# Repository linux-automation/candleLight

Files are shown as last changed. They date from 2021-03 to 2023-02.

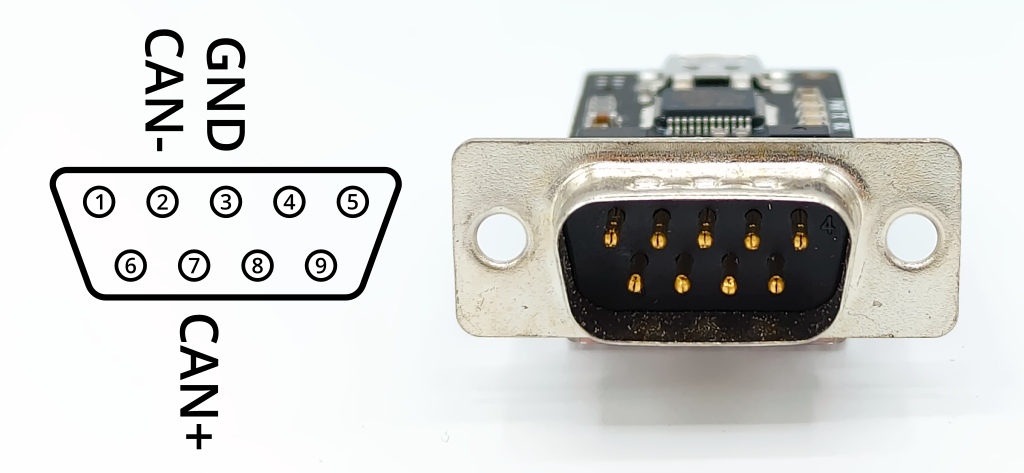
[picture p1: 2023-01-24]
pinout.jpg

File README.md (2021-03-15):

# candleLight

A candleLight is a flash drive sized USB CAN dongle.
It works with the
[candle-usb candleLight firmware](https://github.com/candle-usb/candleLight_fw).

This is a fork of [HubertD's candleLight](https://github.com/HubertD/candleLight)
KiCAD project. Thanks for sharing this awesome design as open hardware!

## Releases

### candlelight-S01-R01

This is our first release for production.

* Added Manufacturer and MPN for key components.
* Added our logo.
* Created manufacturing data.

### V1.1

This is HubertD's original release.

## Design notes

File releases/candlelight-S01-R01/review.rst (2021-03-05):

PCB / PCBA Review Checklists
============================

Schematic Related Topics
------------------------

Drawing
#######

* [x] Are all sheets drawn with the same paper size? Is A4 used if possible?
* [x] Does the title block contain the name of the used git-repository?
* [x] Is the revision count in the title block up to date?
* [x] Are comments added where the schematic is not intuitive?

Nets and hierarchy
###################

* [x] Are all mayor nets named? (Either with a net label or due to the use of buses or hierarchical sheet entries.)
* [x] Are the directions of hierarchical sheet entries set in a meaningful way?

ERC
####

* [-] Does an ERC return errors? Are all severe error commented in the schematic?
      lgo: There is a warning that is not relevant for us and not introduced by us

Meta-Information
################

* [x] Do all symbols of manufacturer parts contain a "Manufacturer" and "MPN" field?
* [-] Are all libraries used from a local checkout of the kicad-ptx-lib or
      a projekt-local library? (Do not use absolute or system-wide paths.)
      lgo: This is an import of an existing project that uses the system-wide library.
           We preserve it this way.

Electrical
##########

* [x] Do all Capacitors have a sufficient voltage derating applied?
      - Electrolyte Capacitors: U_R >= U_max * 1.3
      - Ceramic Capacitors:     U_R >= U_max * 1.5 .. 2
      lgo: [x] Not yet. The CapRatedVoltage field should be added

PCB
----

* [x] Have Vias been untented? (use untent.py)
* [x] Have Planes been rebuild? (use shortcut B in PCBNEW)
* [x] Does the PCB contain a PTXguin?
      lgo: [x] Not yet. Check if it would fit
* [-] Does the PCB has a layer stackup in copper on every layer?
      lgo: [-] Not yet. Check if it would fit
      lgo: Passt nicht. Sind aber nur zwei Layer
* [x] Is the PCB marked with the PCB number in copper on at least one side?
      Additional Marks in Mask or Silkscreen are possible.
* [x] Does a DRC return no severe errors?
      lgo: There is an irrelevant Courtyard overlap
* [-] Are all libraries used from a local checkout of the kicad-ptx-lib or
      a projekt-local library? (Do not use absolute or system-wide paths.)
      lgo: This is an import of an existing project that uses the system-wide library.
           We preserve it this way.
* [x] Have all changes been imported from the schematic?
* [x] Is the auxiliary origin reference point set to a corner of the PCB?
      Preferably on the metric grid.
      Preferably on the lower left corner of the PCB.

Create release
--------------
* [x] Change Status from Draft to Release
* [x] Create new folder in release
* [x] Add release to release management (https://scm.pengutronix.de/cgit/intern/hardware/release_management/)

Manufacturing Data
------------------
Has all manufacturing data been generated?

* Assembly:
  * Output to ./release/assembly/
  * [x] Schematic as PDF: EESCHEMA -> File -> Plot -> PDF -> All Pages
  * [x] BOM for sourcing as CSV: EESCHEMA -> BOM -> Export without plugin active. Use csvbom.py to create CSV BOM
  * (-) Optional: Afterwards convert file to *.xlsx for manufacturing
  * [x] PNP: PCBNEW -> File -> Fabrication Output -> Footprint position file.
        Settings:
        * "One for each side".
        * Activate "Include footprints with SMD pads even if not marked Surface Mount"
  * (-) Optional: Afterwards convert files to *.xlsx for manufacturing
  * [x] Assembly Prints: PCBNEW -> File -> Export SVG. Settings: Color, Print Board Edges, All in one File. Rename each output after it is generated
        * [x] Front Fabrication. Layer: Edge.Cuts, F.Fab
        * [x] Back Fabrication.  Layer: Edge.Cuts, B.Fab
        * [x] Front Silkscreen.  Layer: Edge.Cuts, F.Silk
        * [x] Back Silkscreen.   Layer: Edge.Cuts, B.Silk
* PCB:
  * Drill Data:
    * Output to ./release/pcb/drill
    * [x] Drill Map:
          * [x] Drill-Map PTH as PDF
          * [x] Drill-Map NPTH as PDF
          * PCBNEW -> File -> Fabrication -> Drill Files
          * Settings: Unit:MM, Format:PDF, do not merge PTH and NPTH in one file, deactivate "Do not tent vias"
          * Use "Map-File" Button
    * [x] Actual Drill files:
          * [x] *.drl-File (PTH)
          * [x] *-NPTH.drl-File (NPTH)
          * PCBNEW -> File -> Fabrication -> Drill Files
          * Settings: Unit:MM, Format: PDF, not not merge PTH and NPTH in one file
          * Use "Drill File" Button
          * [x] *.rpt as Drill report and tool legend
          * PCBNEW -> File -> Fabrication -> Drill Files
          * Settings: Unit:MM, Format: PDF, not not merge PTH and NPTH in one file
          * Use "Report File" Button
  * Gerber Data:
    * Output to ./release/pcb/gerber/
    * PCBNEW -> File -> Flot
    * Settings:
      * Plot Format: Gerber
      * Deactivate "Do not tent vias"
      * Deactivate "Exclude PCB edge from other layers"
      * Active "Use Protel filenames"
      * Layers:
        * [x] Cu-Layers depending on Project
        * [x] Paste
        * [x] Silkscreen
        * [x] Mask
        * [x] Uwgs. User (if containing e.g. Size of PCB)
        * [x] Edge.Cuts
 * PCB Data as PDF:
    * Output to ./release/pcb/gerber/
    * PCBNEW -> File -> Flot
    * Settings:
      * Plot Format: PDF
      * Deactivate "Do not tent vias"
      * Deactivate "Exclude PCB edge from other layers"
      * Layers:
        * [x] Cu-Layers depending on Project
        * [x] Paste
        * [x] Silkscreen
        * [x] Mask
        * [x] Uwgs. User (if containing e.g. Size of PCB)
        * [x] Edge.Cuts
  * (-) Test-Data for flying probe:
    * *.cad
    * In PCBNEW -> File -> Export -> GenCAD

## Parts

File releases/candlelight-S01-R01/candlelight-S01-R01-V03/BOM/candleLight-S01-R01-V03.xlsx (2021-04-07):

Company: Linux Automation GmbH
PCBA-Name: candleLight.sch
PCBA-Revision: R01
Placement-Version: V03
PCBA-Title: candleLight
Release-State: released
Release-Date: 2021-04-06
count | reference | manufacturer | mpn | value | description | capratedvoltage | fit | footprint | libref | libsource
1 | X502 | Kobiconn | 156-1209T-E | SUB-D9 |  | nan | all | Connect:DB9M_CI | X | candleLight-rescue:SUB-D9

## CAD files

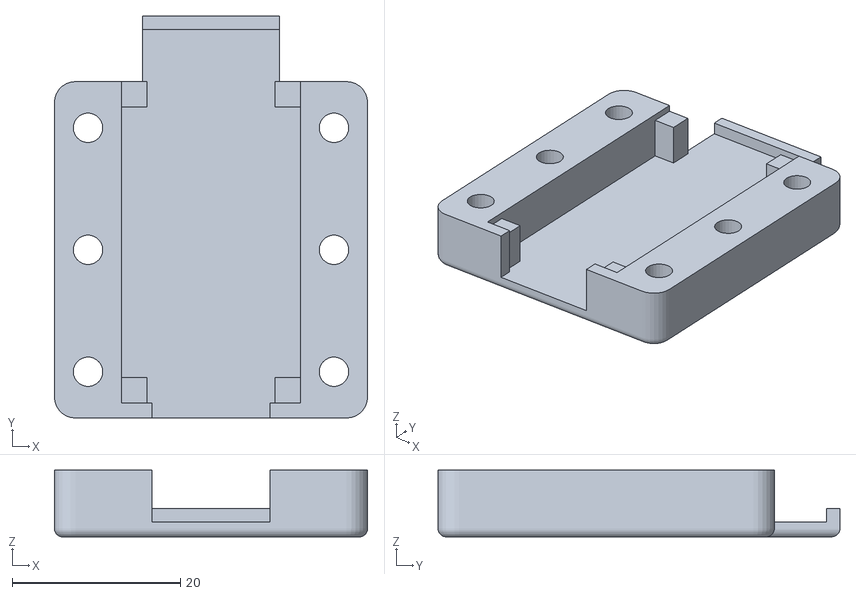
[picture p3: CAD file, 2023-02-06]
case/case_lower.stl
37.2 x 47.8 x 7.95

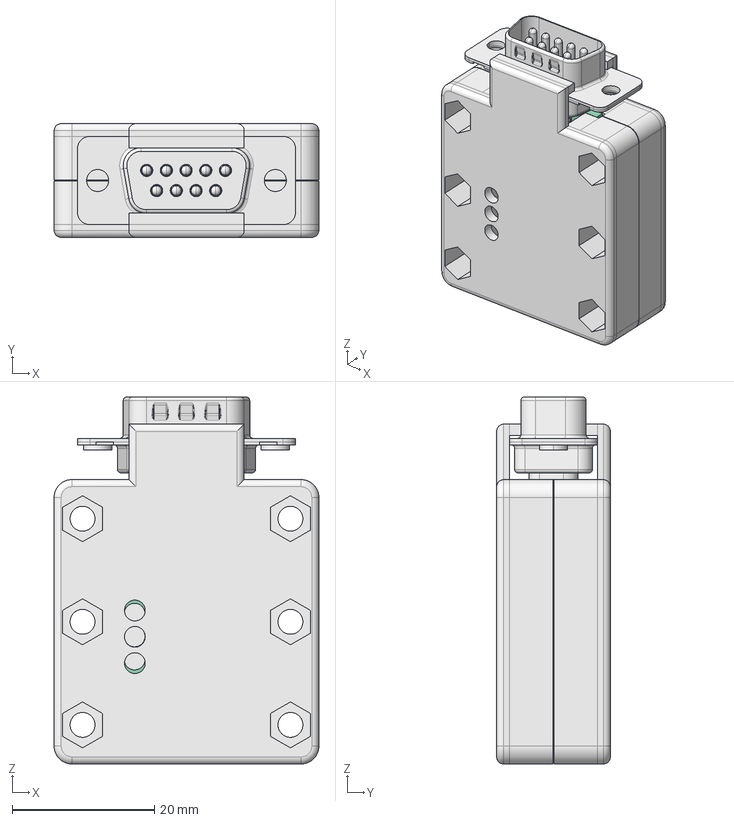
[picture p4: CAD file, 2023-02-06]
case/case.FCStd
37.2 x 16.0 x 51.6 mm
L717DE09P_L777DE09P
Pcb_d466
Unten
Oben001

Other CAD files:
case/case_upper.stl

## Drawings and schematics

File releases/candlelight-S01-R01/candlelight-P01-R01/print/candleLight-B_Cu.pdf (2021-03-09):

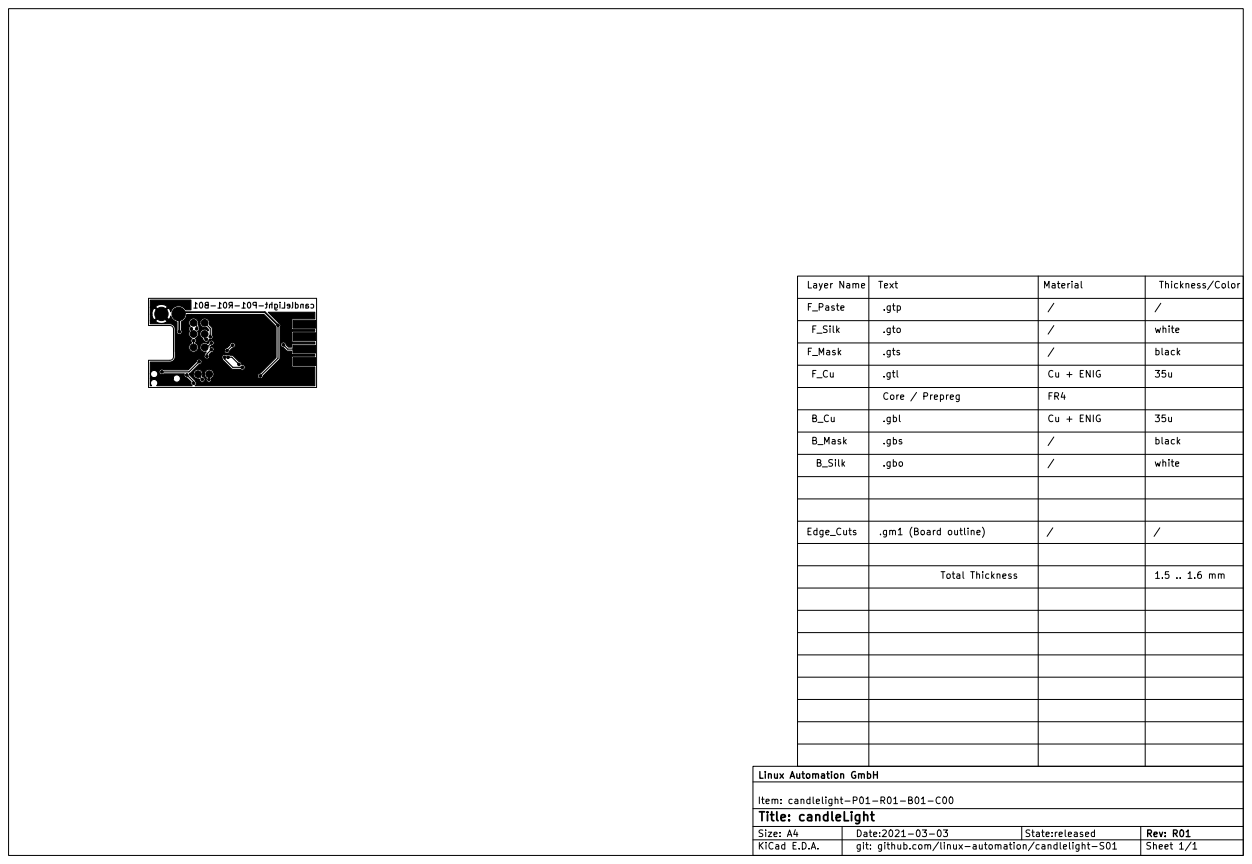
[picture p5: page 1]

git: github.com/linux-automation/candlelight-S01 State:released
Date:2021-03-03

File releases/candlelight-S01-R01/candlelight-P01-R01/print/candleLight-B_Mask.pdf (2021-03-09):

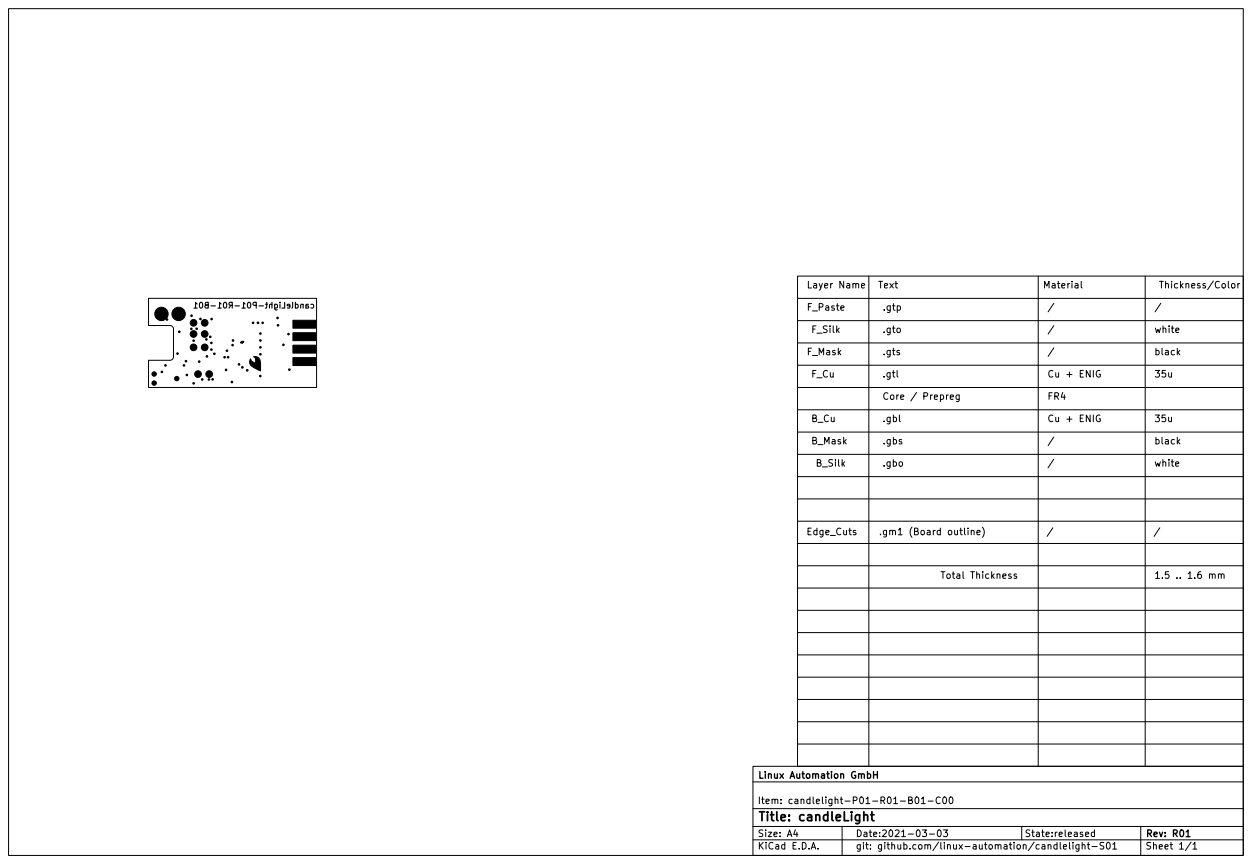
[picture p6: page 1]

git: github.com/linux-automation/candlelight-S01 State:released
Date:2021-03-03

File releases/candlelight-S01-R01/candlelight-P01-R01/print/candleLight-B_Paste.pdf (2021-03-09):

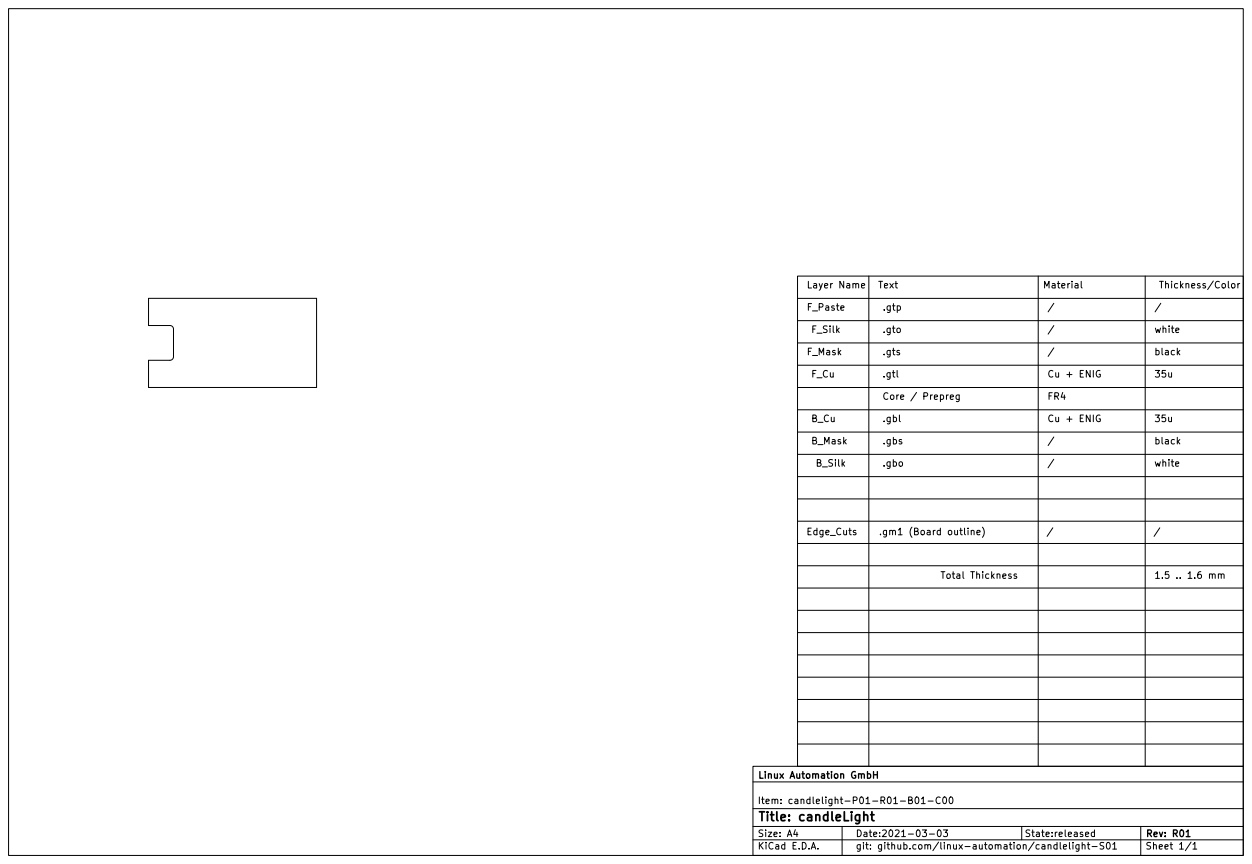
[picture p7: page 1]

git: github.com/linux-automation/candlelight-S01 State:released
Date:2021-03-03

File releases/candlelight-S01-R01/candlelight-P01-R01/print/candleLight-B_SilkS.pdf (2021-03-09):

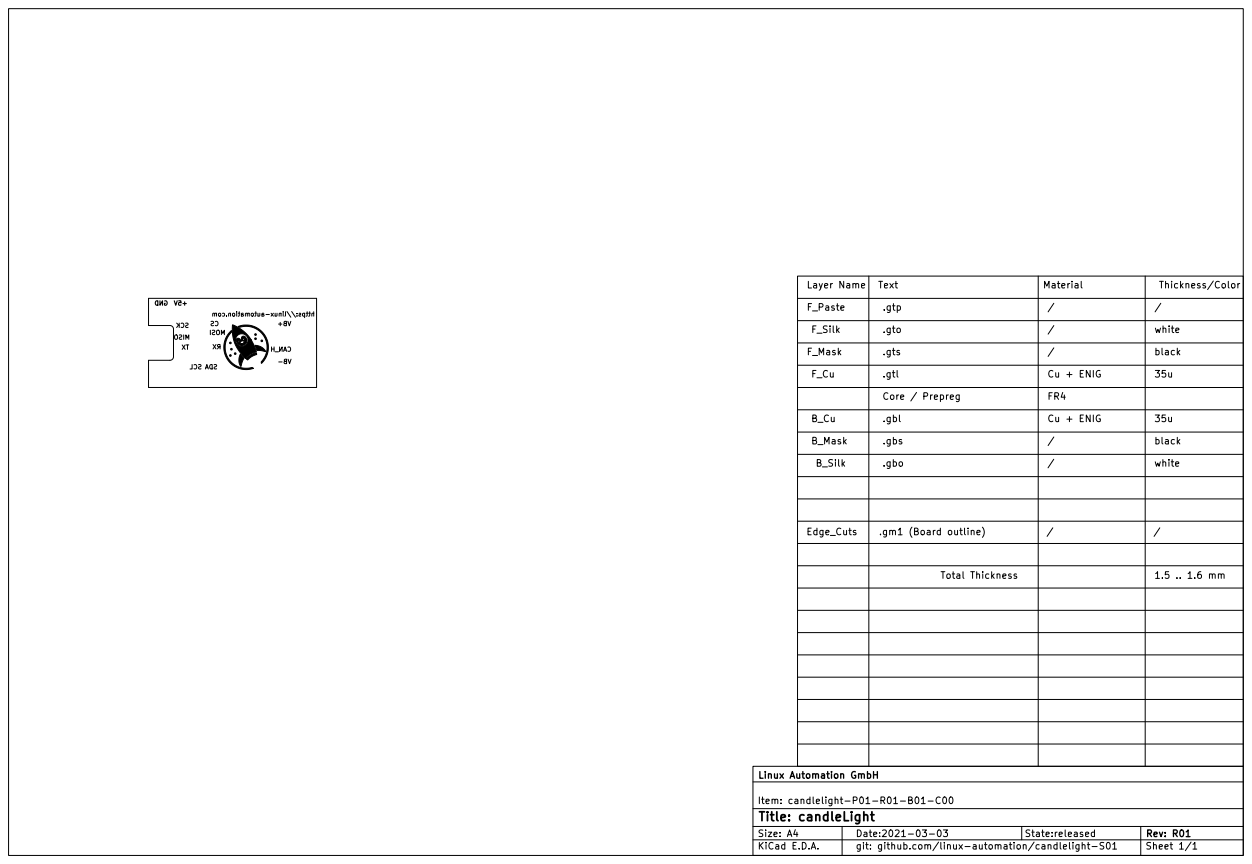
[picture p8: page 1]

git: github.com/linux-automation/candlelight-S01 State:released
Date:2021-03-03

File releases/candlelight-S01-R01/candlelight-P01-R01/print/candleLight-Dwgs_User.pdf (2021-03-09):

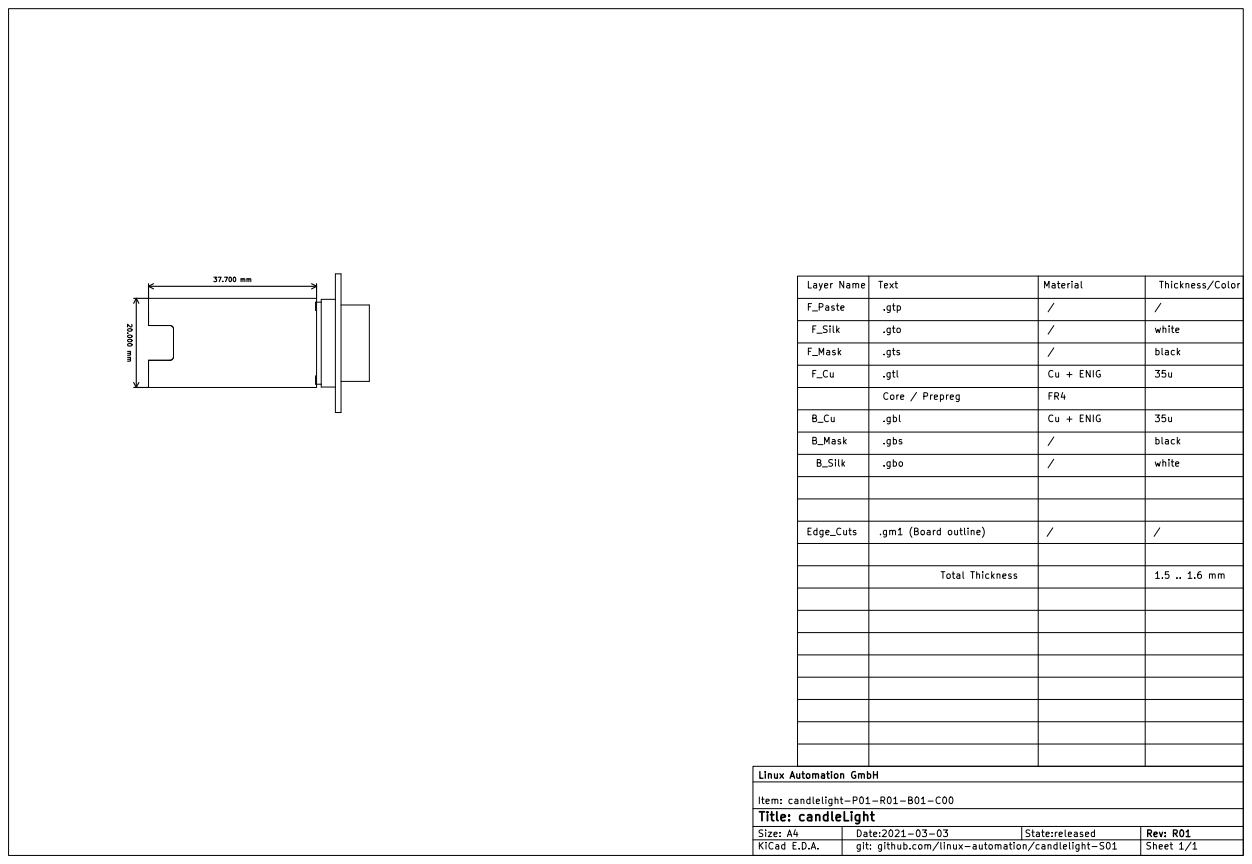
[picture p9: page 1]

git: github.com/linux-automation/candlelight-S01 State:released
Date:2021-03-03

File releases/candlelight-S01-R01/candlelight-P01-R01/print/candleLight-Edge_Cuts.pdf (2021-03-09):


git: github.com/linux-automation/candlelight-S01 State:released
Date:2021-03-03

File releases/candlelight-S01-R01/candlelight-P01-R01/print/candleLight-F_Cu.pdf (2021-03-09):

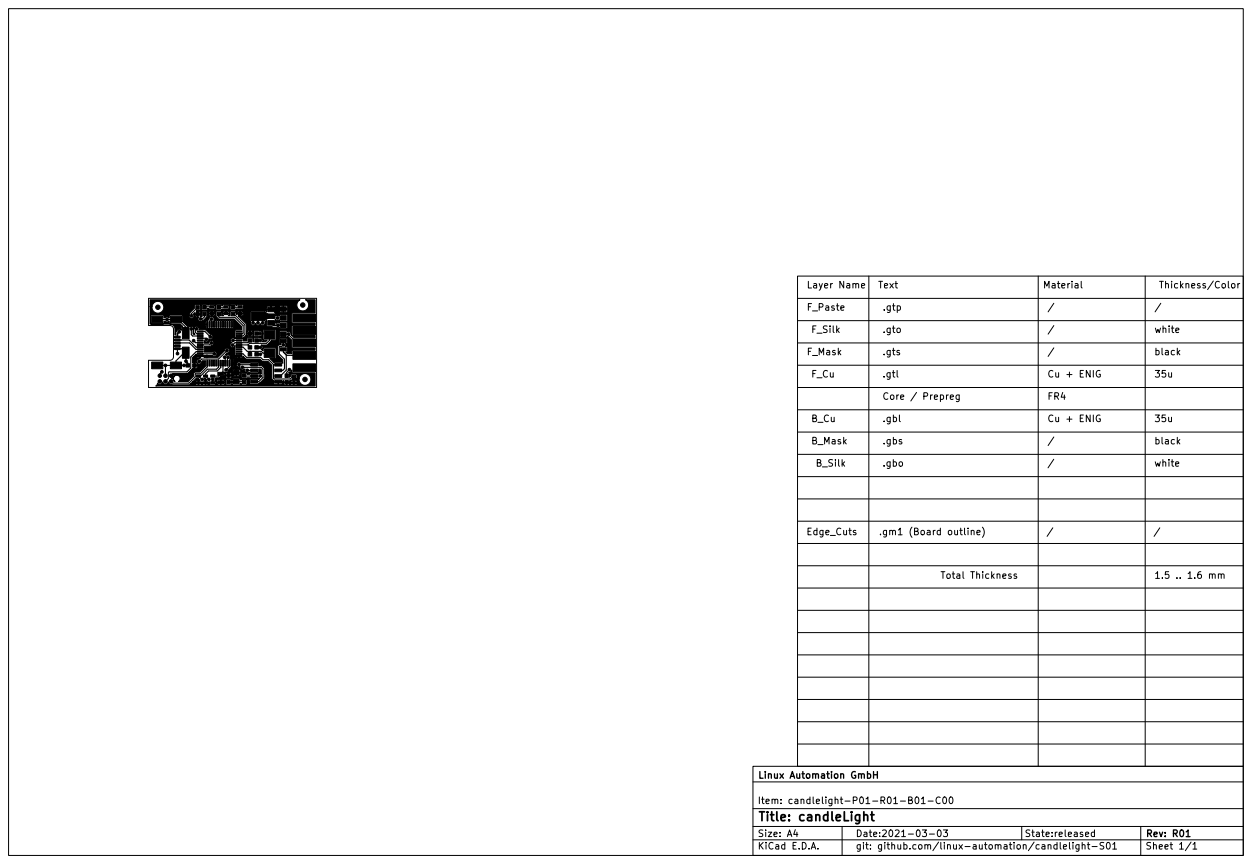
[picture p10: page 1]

git: github.com/linux-automation/candlelight-S01 State:released
Date:2021-03-03

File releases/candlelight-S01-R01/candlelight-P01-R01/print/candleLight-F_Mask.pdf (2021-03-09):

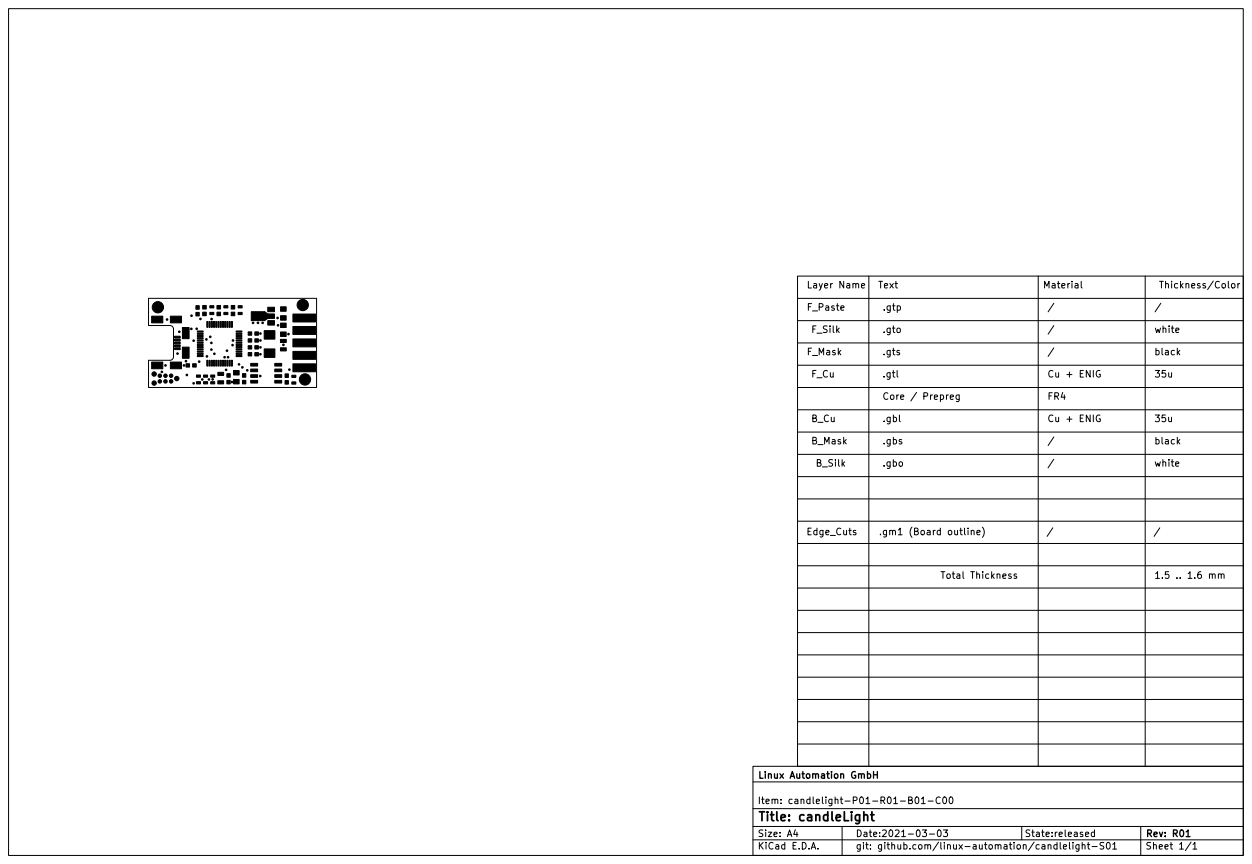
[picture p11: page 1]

git: github.com/linux-automation/candlelight-S01 State:released
Date:2021-03-03

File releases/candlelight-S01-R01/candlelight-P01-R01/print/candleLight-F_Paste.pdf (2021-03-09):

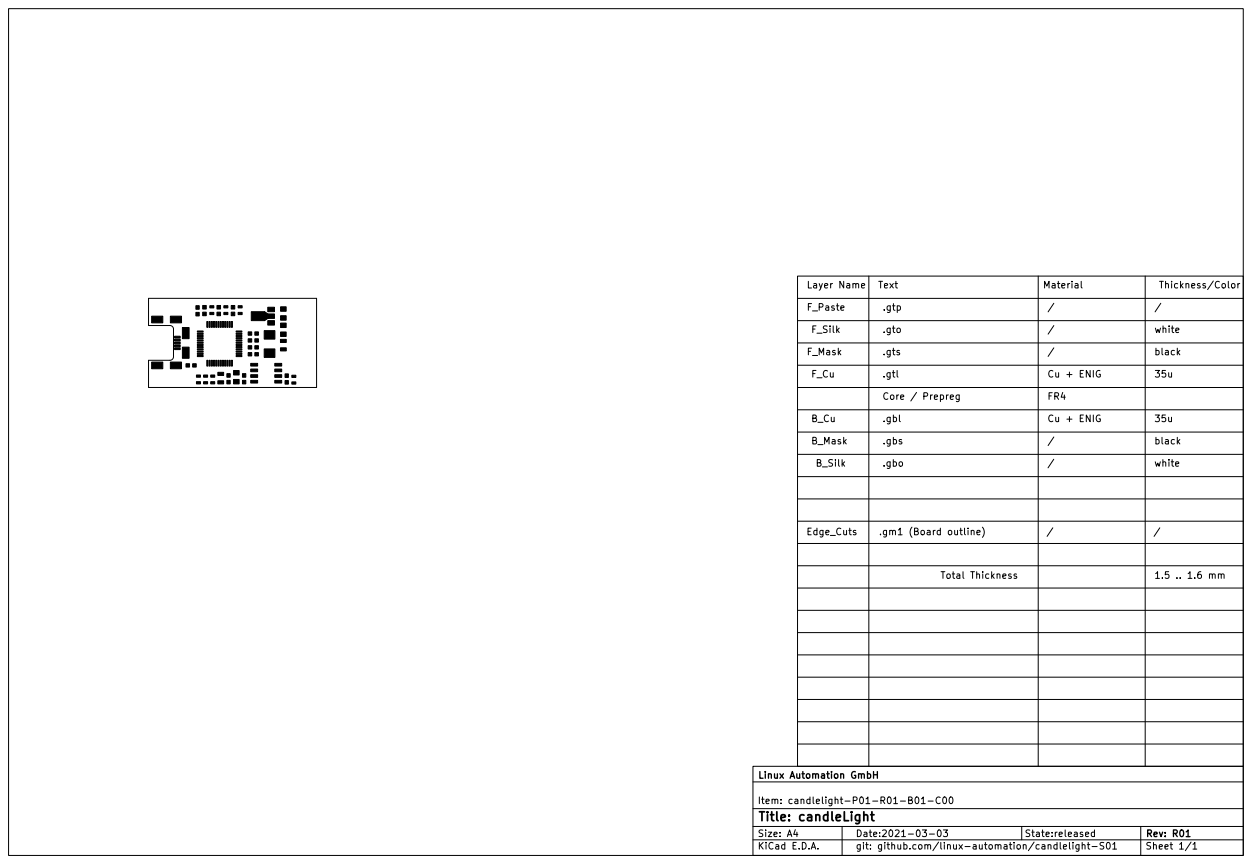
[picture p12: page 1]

git: github.com/linux-automation/candlelight-S01 State:released
Date:2021-03-03

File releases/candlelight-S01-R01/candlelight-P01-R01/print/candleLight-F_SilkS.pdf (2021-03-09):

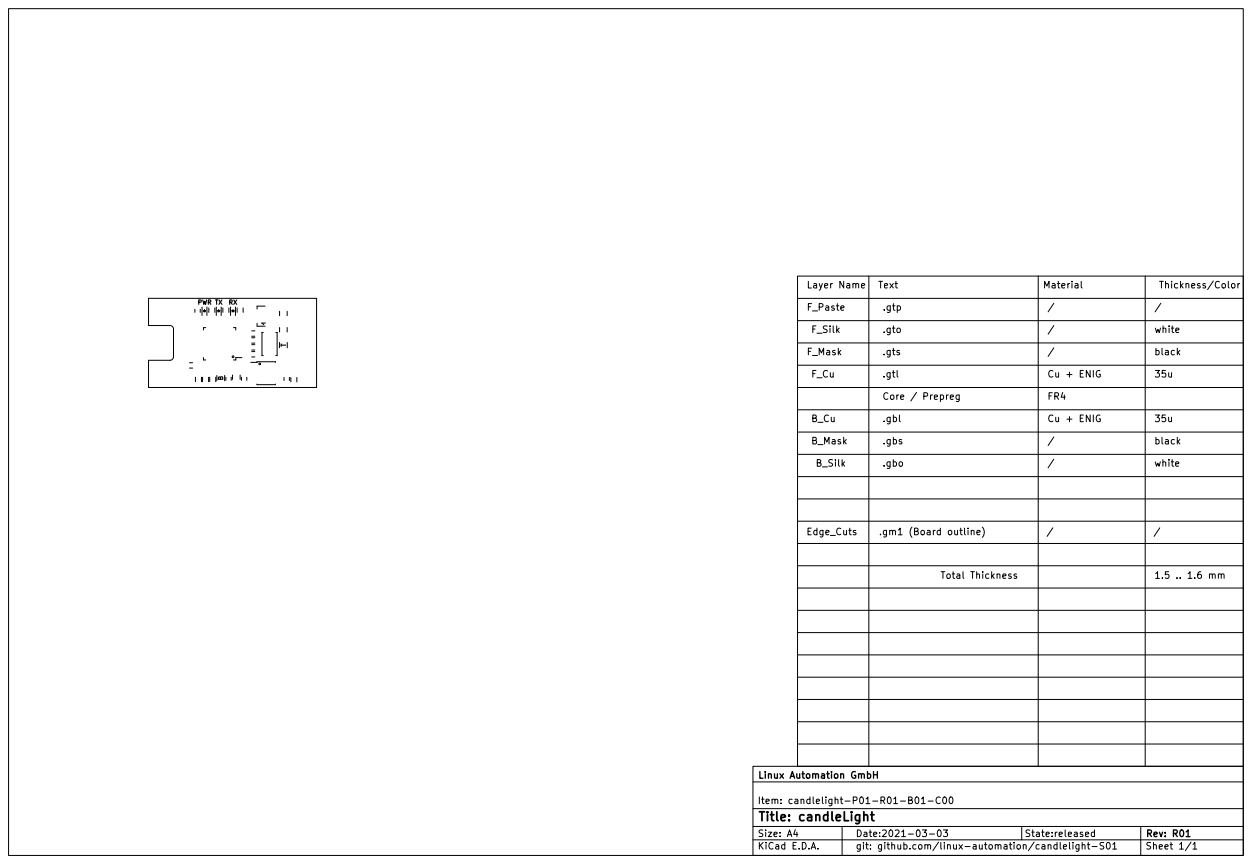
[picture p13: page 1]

git: github.com/linux-automation/candlelight-S01 State:released
Date:2021-03-03

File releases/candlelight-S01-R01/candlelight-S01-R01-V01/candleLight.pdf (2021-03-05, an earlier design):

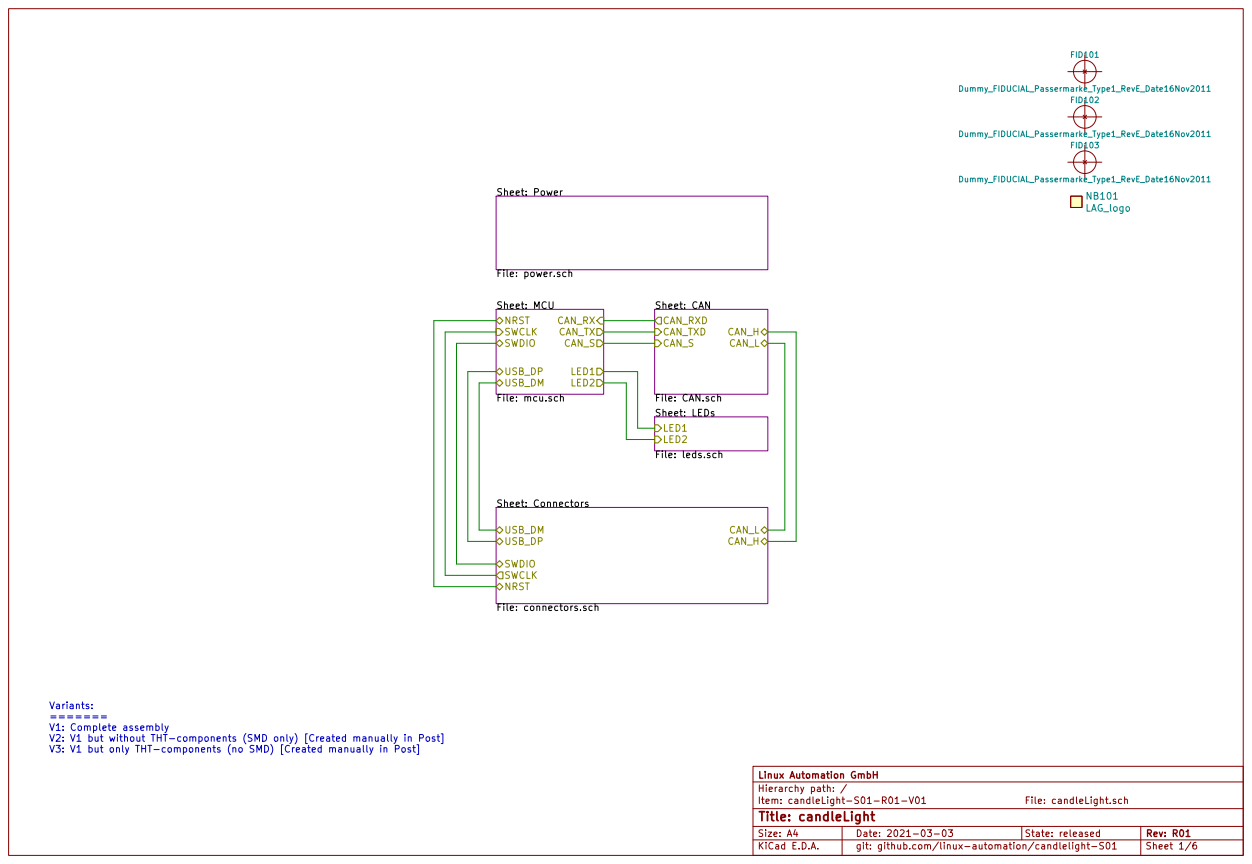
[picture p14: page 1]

Sheet: MCU
File: mcu.sch NRST
SWCLK
SWDIO

File: CAN.sch
Sheet: LEDs File: leds.sch

V2: V1 but without THT-components (SMD only) [Created manually in Post]
V3: V1 but only THT-components (no SMD) [Created manually in Post]

Hierarchy path: / Linux Automation GmbH

git: github.com/linux-automation/candlelight-S01 State: released

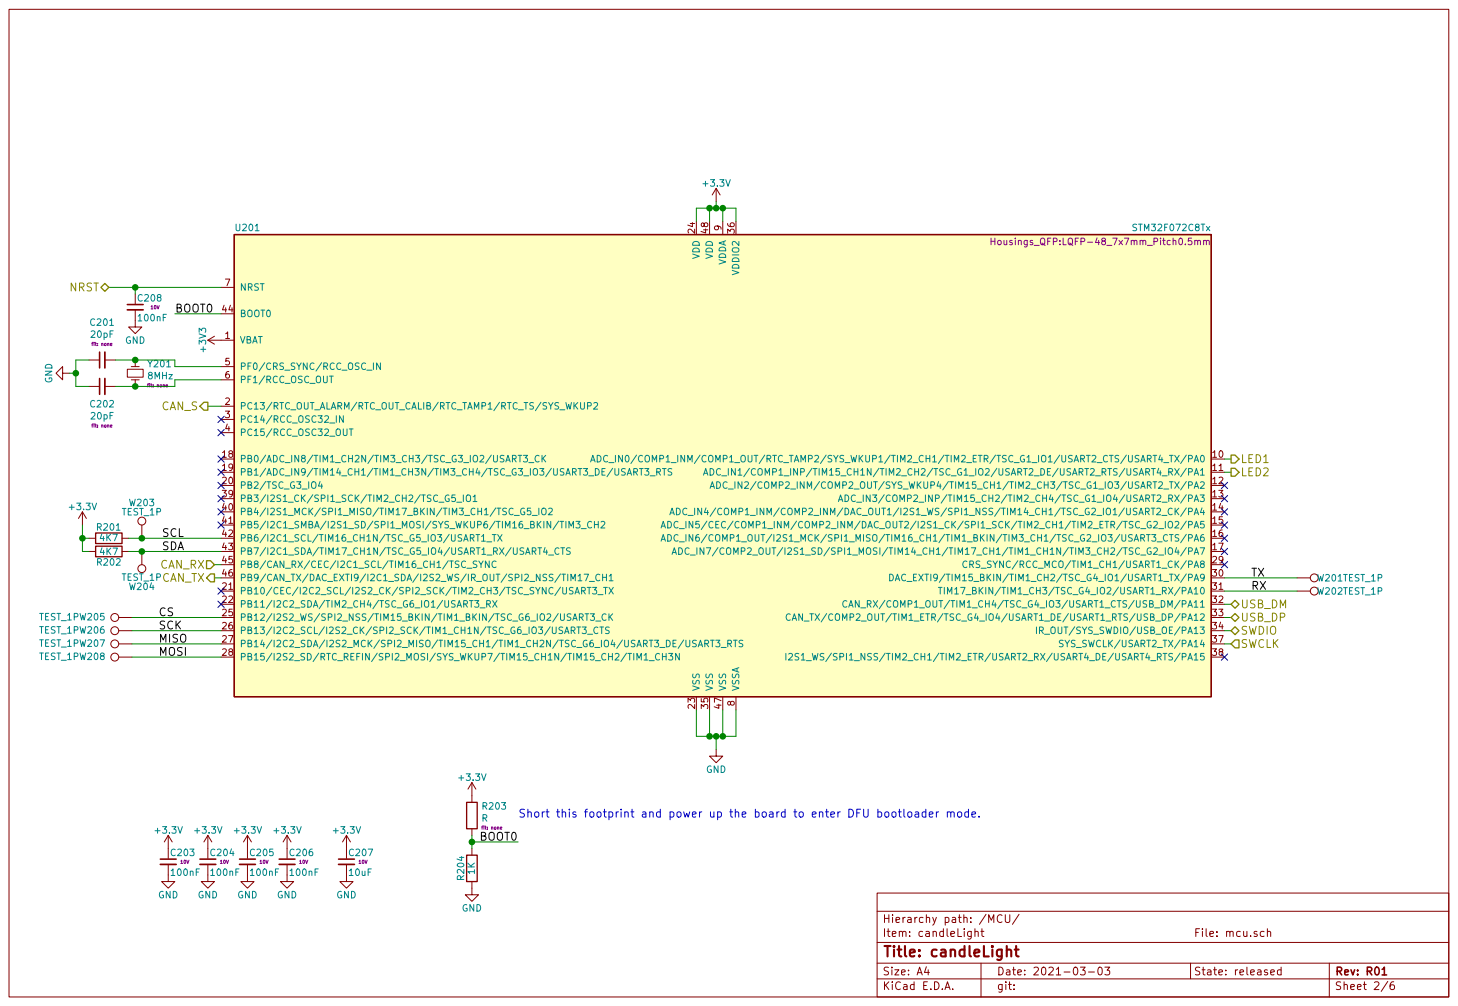
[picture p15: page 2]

Short this footprint and power up the board to enter DFU bootloader mode.
BOOT0

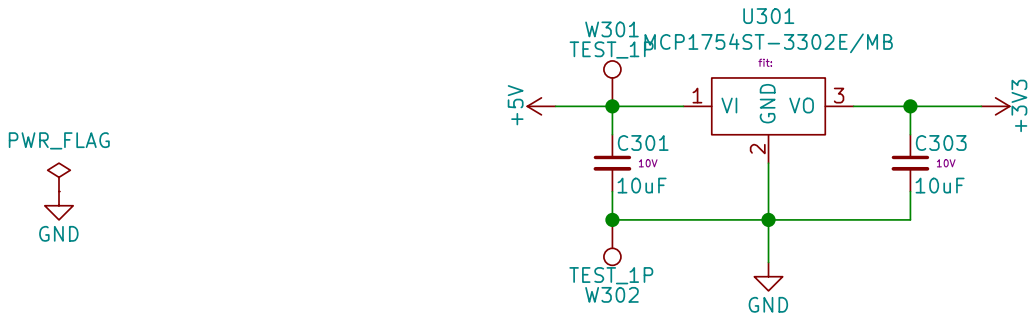
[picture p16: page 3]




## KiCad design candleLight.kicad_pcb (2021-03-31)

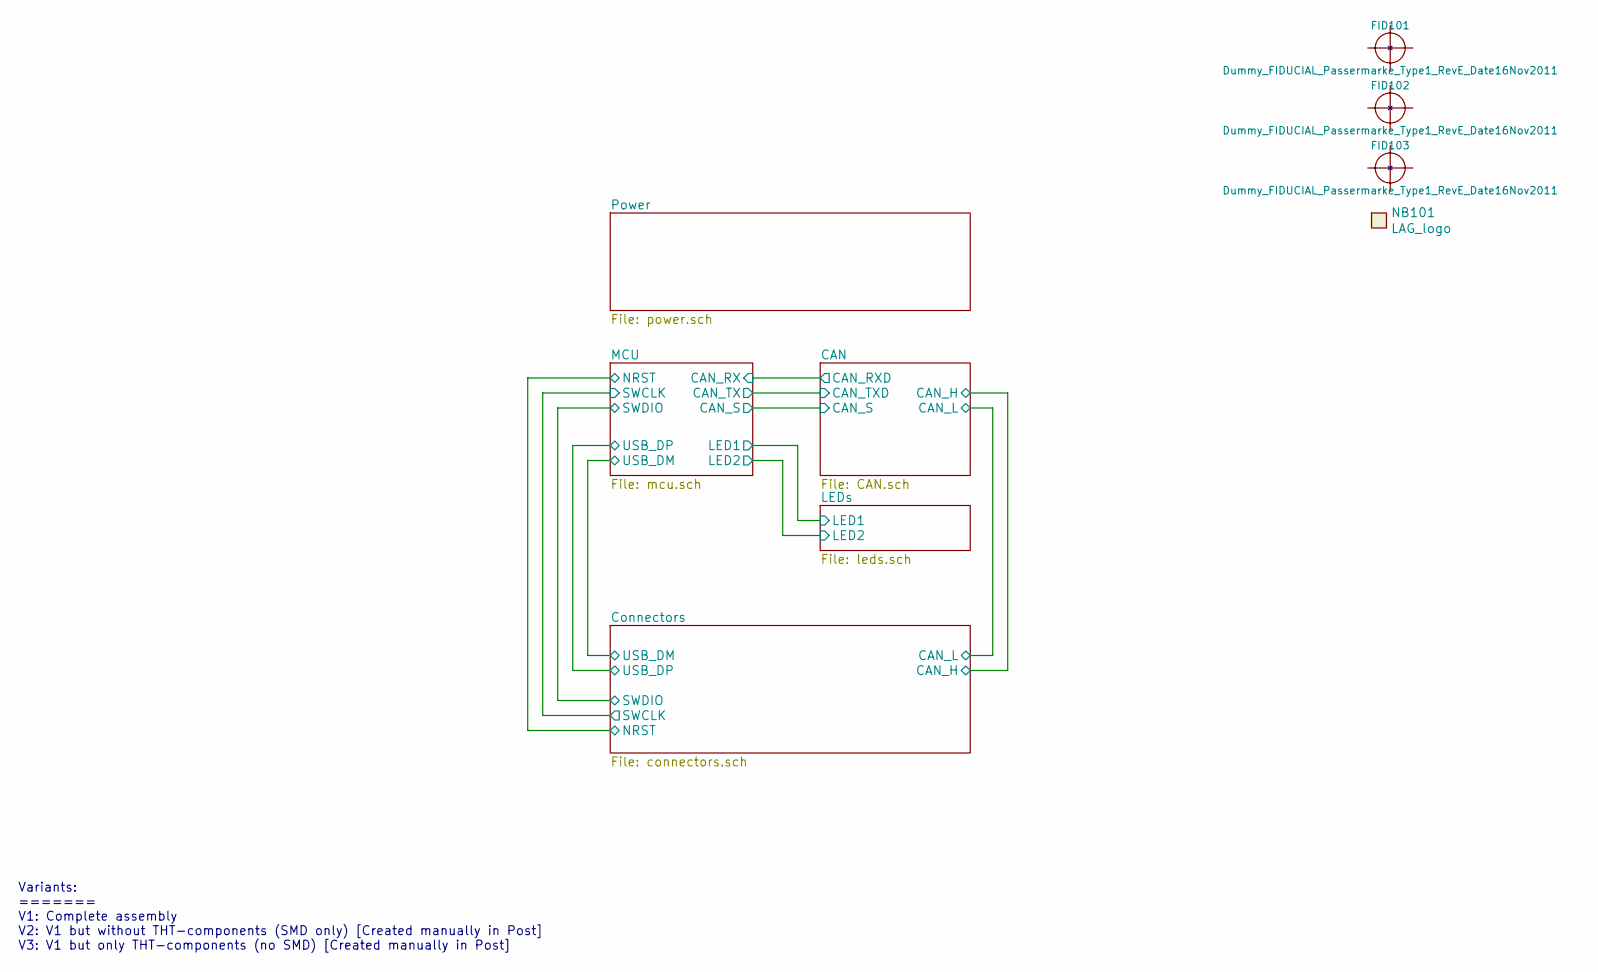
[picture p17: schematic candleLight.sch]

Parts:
FID101, FID102, FID103: Dummy_FIDUCIAL_Passermarke_Type1_RevE_Date16Nov20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; Fiducial_1mm_Dia_2.54mm_Outer_CopperTop
NB101: LAG_logo; lag_rocket_10mmx10.4mm

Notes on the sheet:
Variants: ======= V1: Complete assembly V2: V1 but without THT-components (SMD only) [Created manually in Post] V3: V1 but only THT-components (no SMD) [Created manually in Post]

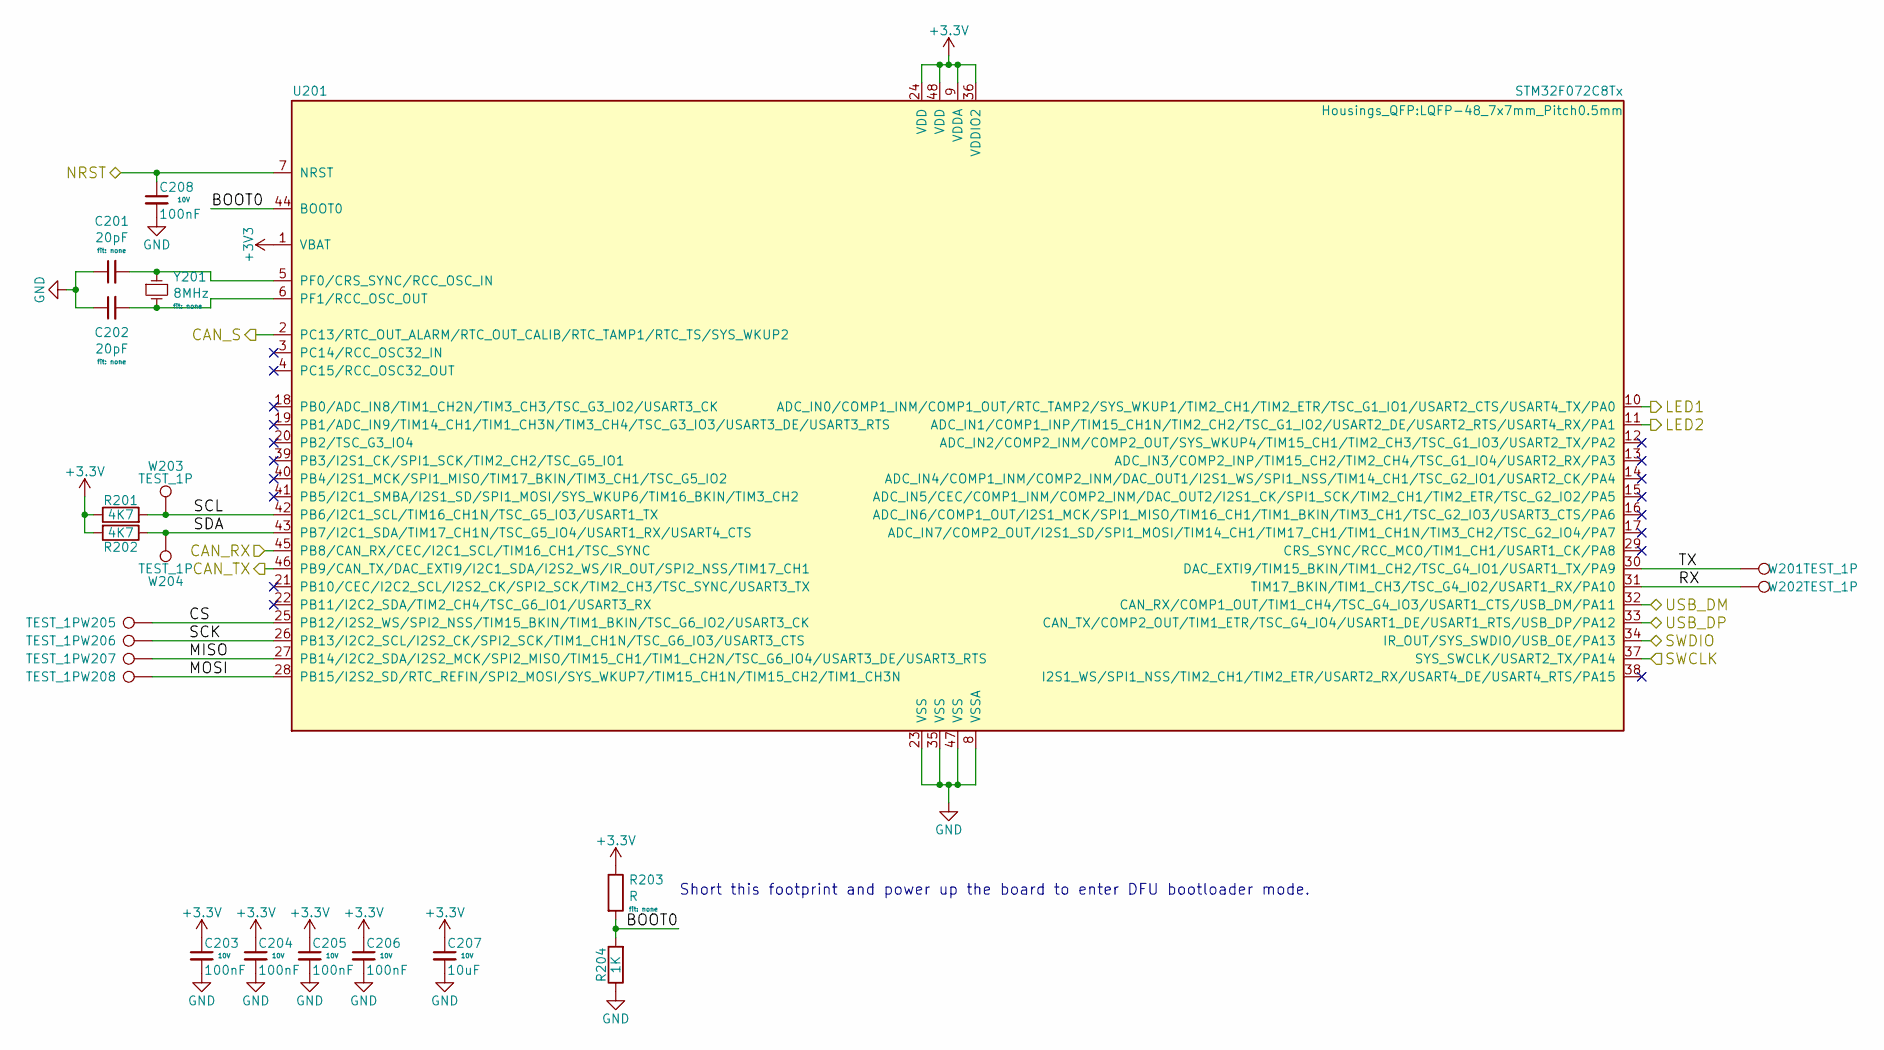
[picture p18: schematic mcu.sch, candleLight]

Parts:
C201, C202: 20pF; C_0603
C203, C204, C205, C206, C208: 100nF; C_0603
C207: 10uF; C_0805
R201, R202: 4K7; R_0603
R203: R; R_0805
R204: 1K; R_0603
U201: STM32F072C8Tx; LQFP-48_7x7mm_Pitch0.5mm; MPN STM32F072C8T6
W201, W202, W203, W204, W205, W206, W207, W208: TEST_1P; Measurement_Point_Round-SMD-Pad_Small
Y201: 8MHz; ABM3

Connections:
/CAN/CAN_S: U201.2 (PC13/RTC_OUT_ALARM/RTC_OUT_CALIB/RTC_TA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); also elsewhere on the board
/Connectors/NRST: C208.1, U201.7 (NRST); also elsewhere on the board
/Connectors/SWCLK: U201.37 (SYS_SWCLK/USART2_TX/PA14); also elsewhere on the board
/Connectors/SWDIO: U201.34 (IR_OUT/SYS_SWDIO/USB_OE/PA13); also elsewhere on the board
/Connectors/USB_DM: U201.32 (CAN_RX/COMP1_OUT/TIM1_CH4/TSC_G4_IO3/US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); also elsewhere on the board
/Connectors/USB_DP: U201.33 (CAN_TX/COMP2_OUT/TIM1_ETR/TSC_G4_IO4/US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); also elsewhere on the board
/LEDs/LED1: U201.10 (ADC_IN0/COMP1_INM/COMP1_OUT/RTC_TAMP2/S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); also elsewhere on the board
/LEDs/LED2: U201.11 (ADC_IN1/COMP1_INP/TIM15_CH1N/TIM2_CH2/T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); also elsewhere on the board
/MCU/BOOT0: R203.2, R204.2, U201.44 (BOOT0)
/MCU/CAN_RX: U201.45 (PB8/CAN_RX/CEC/I2C1_SCL/TIM16_CH1/TSC_S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); also elsewhere on the board
/MCU/CAN_TX: U201.46 (PB9/CAN_TX/DAC_EXTI9/I2C1_SDA/I2S2_WS/I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); also elsewhere on the board
/MCU/CS: U201.25 (PB12/I2S2_WS/SPI2_NSS/TIM15_BKIN/TIM1_B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), W205.1
/MCU/MISO: U201.27 (PB14/I2C2_SDA/I2S2_MCK/SPI2_MISO/TIM15_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), W207.1
/MCU/MOSI: U201.28 (PB15/I2S2_SD/RTC_REFIN/SPI2_MOSI/SYS_WK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), W208.1
/MCU/RX: U201.31 (TIM17_BKIN/TIM1_CH3/TSC_G4_IO2/USART1_R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), W202.1
/MCU/SCK: U201.26 (PB13/I2C2_SCL/I2S2_CK/SPI2_SCK/TIM1_CH1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), W206.1
/MCU/SCL: R201.2, U201.42 (PB6/I2C1_SCL/TIM16_CH1N/TSC_G5_IO3/USAR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), W203.1
/MCU/SDA: R202.1, U201.43 (PB7/I2C1_SDA/TIM17_CH1N/TSC_G5_IO4/USAR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), W204.1
/MCU/TX: U201.30 (DAC_EXTI9/TIM15_BKIN/TIM1_CH2/TSC_G4_IO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), W201.1
GND: C201.1, C202.1, C203.2, C204.2, C205.2, C206.2, C207.2, C208.2, R204.1, U201.8 (VSSA), U201.23 (VSS), U201.35 (VSS), U201.47 (VSS); also elsewhere on the board
unnamed: C201.2, U201.5 (PF0/CRS_SYNC/RCC_OSC_IN), Y201.1
unnamed: C202.2, U201.6 (PF1/RCC_OSC_OUT), Y201.2

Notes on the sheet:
Short this footprint and power up the board to enter DFU bootloader mode.

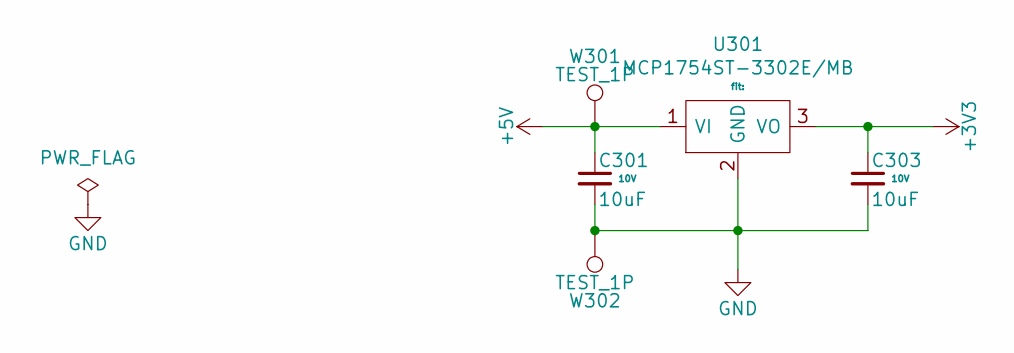
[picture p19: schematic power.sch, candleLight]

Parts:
C301, C303: 10uF; C_0805
U301: MCP1754ST-3302E/MB; SOT89-3_Housing; MPN MCP1754ST-3302E/MB
W301, W302: TEST_1P; Measurement_Point_Round-SMD-Pad_Big

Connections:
+5V: C301.1, U301.1 (VI), W301.1; also elsewhere on the board
GND: C301.2, C303.2, U301.2 (GND), W302.1; also elsewhere on the board

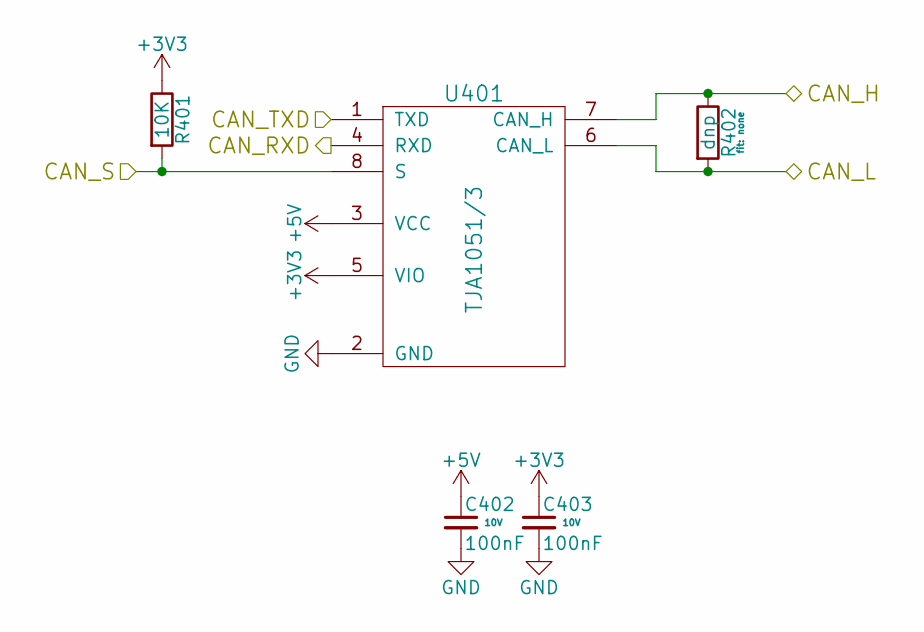
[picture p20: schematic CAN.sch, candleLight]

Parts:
C402, C403: 100nF; C_0603
R401: 10K; R_0603
R402: dnp; R_0805
U401: TJA1051/3; SOIC-8_3.9x4.9mm_Pitch1.27mm; MPN TJA1051T/3/1J

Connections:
+5V: C402.1, U401.3 (VCC); also elsewhere on the board
/CAN/CAN_H: R402.1, U401.7 (CAN_H); also elsewhere on the board
/CAN/CAN_L: R402.2, U401.6 (CAN_L); also elsewhere on the board
/CAN/CAN_S: R401.2, U401.8 (S); also elsewhere on the board
/MCU/CAN_RX: U401.4 (RXD); also elsewhere on the board
/MCU/CAN_TX: U401.1 (TXD); also elsewhere on the board
GND: C402.2, C403.2, U401.2 (GND); also elsewhere on the board

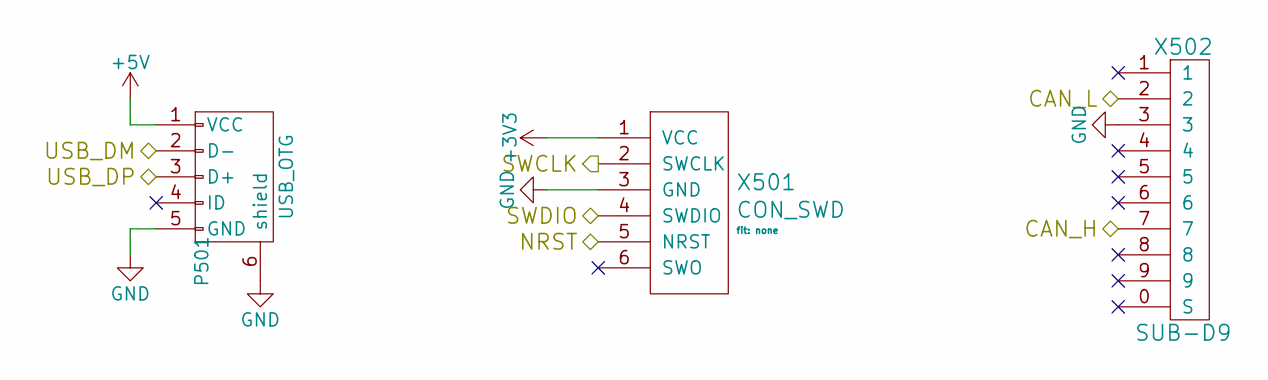
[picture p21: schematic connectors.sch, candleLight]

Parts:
P501: USB_OTG; Molex-Micro-USB-B-Middle-Mount; MPN 47491-0001
X501: CON_SWD; TC2030-NL
X502: SUB-D9; DB9M_CI; MPN 156-1209T-E

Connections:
+5V: P501.1 (VCC); also elsewhere on the board
/CAN/CAN_H: X502.7; also elsewhere on the board
/CAN/CAN_L: X502.2; also elsewhere on the board
/Connectors/NRST: X501.5 (NRST); also elsewhere on the board
/Connectors/SWCLK: X501.2 (SWCLK); also elsewhere on the board
/Connectors/SWDIO: X501.4 (SWDIO); also elsewhere on the board
/Connectors/USB_DM: P501.2 (D-); also elsewhere on the board
/Connectors/USB_DP: P501.3 (D+); also elsewhere on the board
GND: P501.5 (GND), P501.6 (shield), X501.3 (GND), X502.3; also elsewhere on the board

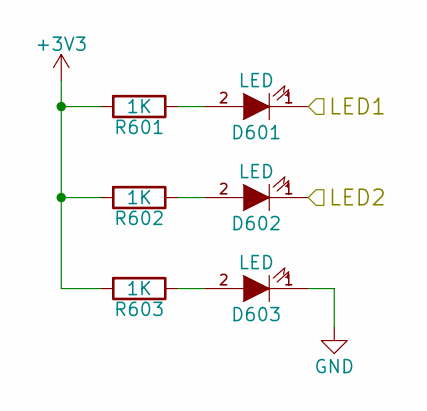
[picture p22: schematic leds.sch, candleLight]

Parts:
D601: LED; LED_0603; MPN APT1608SGC
D602: LED; LED_0603; MPN APT1608YC
D603: LED; LED_0603; MPN APT1608EC
R601, R602, R603: 1K; R_0603

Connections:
/LEDs/LED1: D601.1 (K); also elsewhere on the board
/LEDs/LED2: D602.1 (K); also elsewhere on the board
GND: D603.1 (K); also elsewhere on the board
unnamed: D601.2 (A), R601.1
unnamed: D602.2 (A), R602.1
unnamed: D603.2 (A), R603.1

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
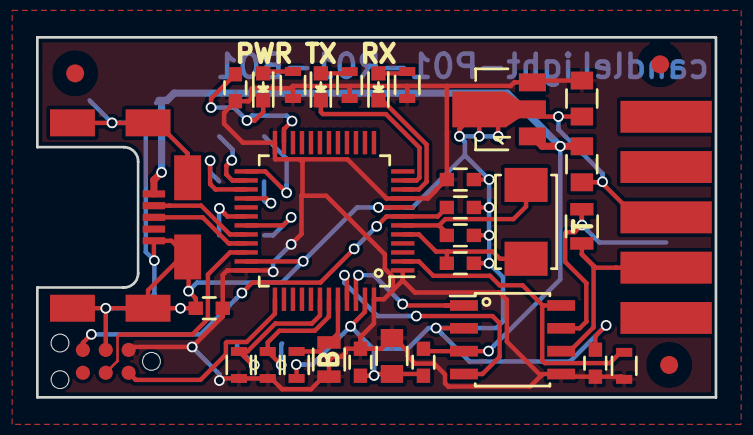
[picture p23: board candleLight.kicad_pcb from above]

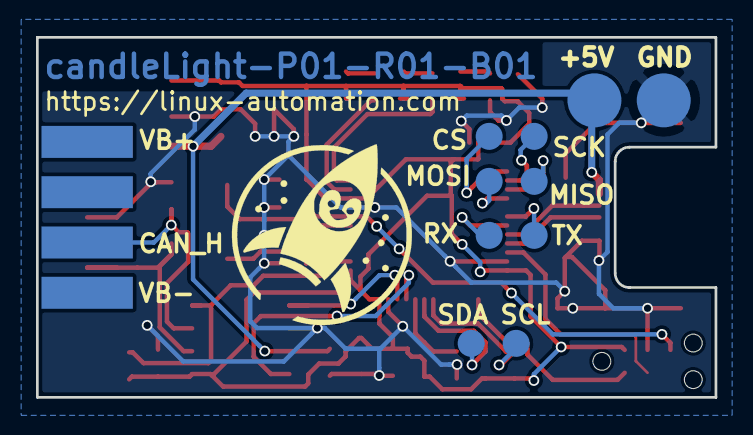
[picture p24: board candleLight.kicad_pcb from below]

Board: 2 copper layers, 37.7 x 20.0 mm, 45 parts (11 on the bottom side), 29 nets.

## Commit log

2021-03-03 Perform automatic KiCAD rescue operations
    [candleLight.kicad_pcb]
2021-03-03 Add Linux Automation page layout
    [CAN.sch, candleLight.kicad_pcb, candleLight.sch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]
2021-03-03 Add Fit, Manufacturer, MPN fields
    [CAN.sch, candleLight.sch, connectors.sch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]
2021-03-04 Update Silkscreen and add netnames
    [candleLight.kicad_pcb, leds.sch, mcu.sch]
2021-03-04 Add Cap voltage rating, Put PCB ref on cupper, add note for variants
    [CAN.sch, candleLight.kicad_pcb, candleLight.sch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]
2021-03-04 Add linux automation logo
    [candleLight.kicad_pcb, candleLight.sch]
2021-03-05 Create release candlelight-S01-R01
    [candleLight-B_Cu.gbl, candleLight-B_Mask.gbs, candleLight-B_Paste.gbp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]
2021-03-08 Fix candlelight-S01-R01-V03: mixup USB/D-SUB
    [candleLight-S01-R01-V03.csv]
2021-03-08 Remove original manufacturing data
    The original manufacturing data does not match our
    versioning scheme and we are not going to support
    hardware manufactured based on it.
    Remove it to prevent confusing people looking for
    the manufacturing data corresponding to the product
    they bought in our shop.
    [candleLight-v1.1.xls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]
2021-03-08 Add PnP information to SMT variant and check BoM completeness
2021-03-09 pcb: Add Layer Stack to drawing frame and regenerate gerber
    [candleLight-B_Cu.gbl, candleLight-B_Mask.gbs, candleLight-B_Paste.gbp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]
2021-03-22 S01-R01: Add BOM as XLS
    [candleLight-S01-R01-V01.xlsx, candleLight-S01-R01-V02.xlsx]
2021-03-31 Micro-USB socket was marked as THT not SMD. Fixed PnP
    [candleLight.kicad_pcb]
2021-04-07 Fix BOM in release R01
    [candleLight-S01-R01-V01.csv, candleLight-S01-R01-V01.xlsx, candleLight-S01-R01-V02.csv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]
2021-06-09 release: Add GenCad Flying probe data
2023-02-06 Add 3D-printable case
    This is a FreeCAD model of a 3d-printable case for the candlelight.
    It is intended to be printed with ABS or PETG and to mechanically
    protect the candlelight.
    Boths halfs can be screwed together using 2 or 4 M3x8mm cylinder head
    scrwes.
    LEDs are still somewhat visible through holes in the upper part of the
    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
    [case.FCStd, case_lower.stl, case_upper.stl]
